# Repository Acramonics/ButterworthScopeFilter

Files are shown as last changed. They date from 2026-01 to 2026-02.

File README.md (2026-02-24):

ScopeFilter
===========

Andrew Martin, Acramonics, January 2026
---------------------------------------

This ScopeFilter is designed for putting in front of an oscilloscope
when doing audio work where there is HF interference from computers,
etc. It is a simple Active Butterworth dual 2nd order filter with a
cutoff of 50kHz.

It is powered by a standard 9v wallwart with the power supply section
taken from the Elektor ESR meter giving positive and negative 4.5v
rails.

Filter component values are calculated from
https://www.changpuak.ch/electronics/Butterworth_Lowpass_active_24dB.php
and tweaked to standard values. As specified, the filter starts to cut
off at 40kHz.

The `LTSpice` directory contains an LTSpice simulation showing the
frequency response. The Kicad Spice simulator seems to have difficulty
with dual rail power supplies.

The `FrontPanelDesigner` directory contains a simple front panel
layout for use with a small aluminium case (W:3.25" H:1.25" x D:4").
The software is available from schaeffer-ag.de/en/front-panel-designer

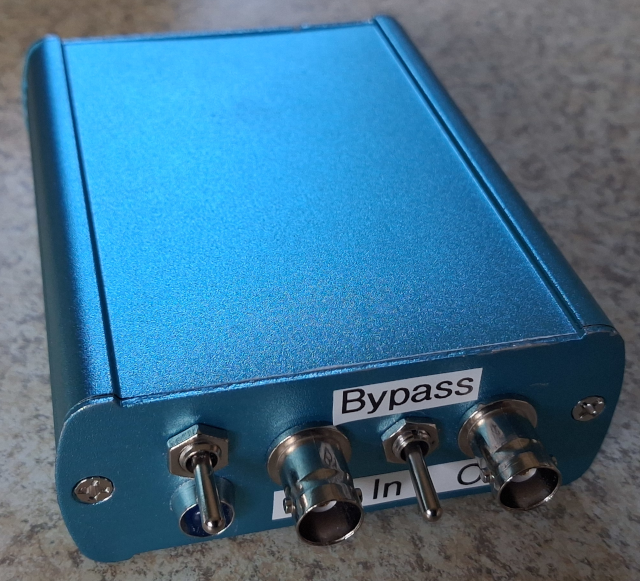
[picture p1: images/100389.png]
Front/top view

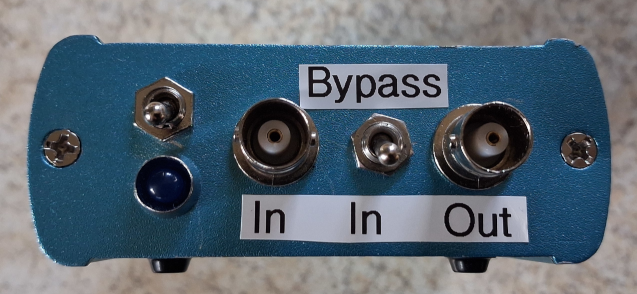
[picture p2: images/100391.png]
Front view

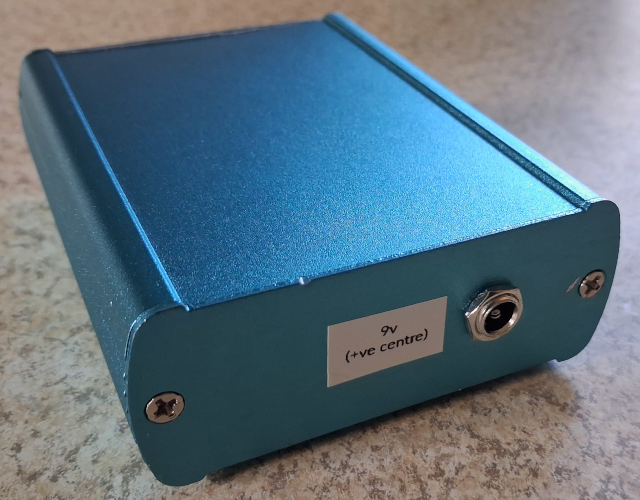
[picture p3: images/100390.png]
Rear view


I built the filter without Molex 254s for any of the wires except the
power input. This is the only one that comes from the back making it
convenient (with long enough wires) to be able to take off the front
panel (which is closely connected to the PCB) and unplug the power
from the board.

These images are generated by Kicad:

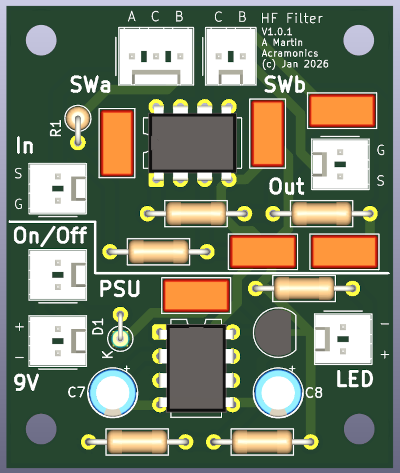
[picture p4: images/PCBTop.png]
PCB top view

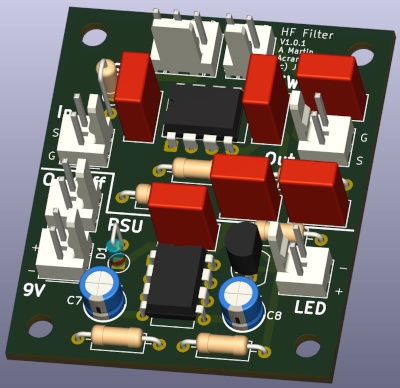
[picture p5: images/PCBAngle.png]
PCB andgle view


With the exception of the two 100nF caps, I also ended up building the
board with 5mm ceramic caps in place of the box film caps shown.

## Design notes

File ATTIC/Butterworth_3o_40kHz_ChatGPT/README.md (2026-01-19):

Filter type: 3rd-order Butterworth LPF

Cutoff: 40 kHz

Order:

2nd-order Sallen-Key (Q = 0.707)

1st-order active pole

Roll-off: −60 dB/decade

Op-amp GBW: ≥ 5 MHz recommended

Op-Amp Requirements (Important)
Because 40 kHz is relatively high for active filters:

GBW ≥ 5 MHz

Slew Rate ≥ 5 V/µs

✅ Recommended:

OPA2134

TL072

NE5532

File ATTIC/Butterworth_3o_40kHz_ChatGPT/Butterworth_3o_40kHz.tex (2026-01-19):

\documentclass[border=10pt]{standalone}
\usepackage{circuitikz}
\usepackage{siunitx}

\begin{document}

\begin{circuitikz}[american]

% ---------- Stage 1: 2nd-order Sallen-Key Butterworth ----------

\node (Vin) at (0,0) {$V_{in}$};
\draw (Vin) to[short] (1,0);

\draw (1,0) to[R=$R_1\,3.9\,\mathrm{k}\Omega$] (3,0);
\draw (3,0) to[R=$R_2\,3.9\,\mathrm{k}\Omega$] (5,0);

\draw (3,0) to[C=$C_1\,1\,\mathrm{nF}$] (3,-2) node[ground]{};
\draw (5,0) to[C=$C_2\,1\,\mathrm{nF}$] (5,-2) node[ground]{};

\draw (5,0) to[short] (6,0);

\node[op amp] (op1) at (7.5,-1) {};
\draw (6,0) |- (op1.+);

\draw (op1.-) to[R=$R_g\,10\,\mathrm{k}\Omega$] (6,-3) node[ground]{};
\draw (op1.out) to[R=$R_f\,5.9\,\mathrm{k}\Omega$] (op1.-);

\draw (op1.out) to[short] (9, -1) node[right]{$V_1$};

% ---------- Stage 2: 1st-order Active LPF ----------

\draw (9,-1) to[R=$R_3\,3.9\,\mathrm{k}\Omega$] (11,-1);
\draw (11,-1) to[C=$C_3\,1\,\mathrm{nF}$] (11,-3) node[ground]{};

\node[op amp] (op2) at (13,-2) {};
\draw (11,-1) |- (op2.+);

\draw (op2.-) to[short] (12,-4) node[ground]{};
\draw (op2.out) to[short] (15,-2) node[right]{$V_{out}$};

\end{circuitikz}

\end{document}

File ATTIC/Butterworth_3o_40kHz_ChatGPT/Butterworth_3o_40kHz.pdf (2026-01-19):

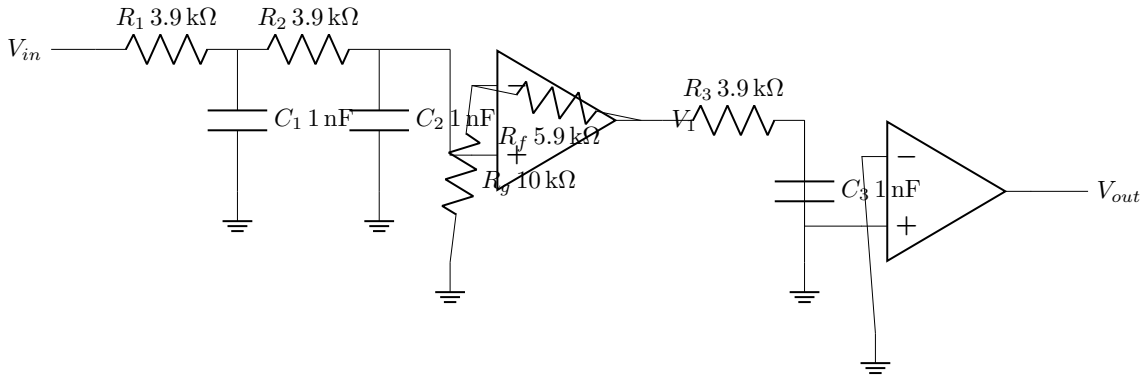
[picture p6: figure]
Vin; Vout

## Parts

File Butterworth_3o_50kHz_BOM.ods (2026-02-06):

Reference | Qty | Value | Footprint
C1,C2 | 2 | 3.3nF | Capacitor_THT:C_Rect_L7.0mm_W3.5mm_P5.00mm
C3 | 1 | 8.2nF | Capacitor_THT:C_Rect_L7.0mm_W3.5mm_P5.00mm
C4 | 1 | 1.2nF | Capacitor_THT:C_Rect_L7.0mm_W3.5mm_P5.00mm
C5,C6 | 2 | 100nF | Capacitor_THT:C_Rect_L7.0mm_W3.5mm_P5.00mm
C7 | 1 | 10uF | Capacitor_THT:CP_Radial_D5.0mm_P2.00mm
C8 | 1 | 22uF | Capacitor_THT:CP_Radial_D5.0mm_P2.00mm
D1 | 1 | 1N4007 | Diode_THT:D_DO-35_SOD27_P2.54mm_Vertical_AnodeUp
D2 | 1 | LED
J1,J2,J4,J5,J6,J7 | 6 | Conn_01x02_Pin | Connector_Molex:Molex_KK-254_AE-6410-02A_1x02_P2.54mm_Vertical
J3 | 1 | Conn_01x03_Pin | Connector_Molex:Molex_KK-254_AE-6410-03A_1x03_P2.54mm_Vertical
J8 | 1 | Barrel_Jack
R1 | 1 | 1K | Resistor_THT:R_Axial_DIN0207_L6.3mm_D2.5mm_P2.54mm_Vertical
R2,R3,R4 | 3 | 1K | Resistor_THT:R_Axial_DIN0207_L6.3mm_D2.5mm_P10.16mm_Horizontal
R5 | 1 | 680R | Resistor_THT:R_Axial_DIN0207_L6.3mm_D2.5mm_P10.16mm_Horizontal
R6 | 1 | 220R | Resistor_THT:R_Axial_DIN0207_L6.3mm_D2.5mm_P10.16mm_Horizontal
R7 | 1 | 330R | Resistor_THT:R_Axial_DIN0207_L6.3mm_D2.5mm_P10.16mm_Horizontal
SW1 | 1 | SW_DPDT_x2
SW2 | 1 | SW_SPST
U1 | 1 | TL072 | Package_DIP:DIP-8_W7.62mm
U2 | 1 | LM317L_TO92 | Package_TO_SOT_THT:TO-92_Inline
U3 | 1 | LMC7660 | Package_DIP:DIP-8_W7.62mm

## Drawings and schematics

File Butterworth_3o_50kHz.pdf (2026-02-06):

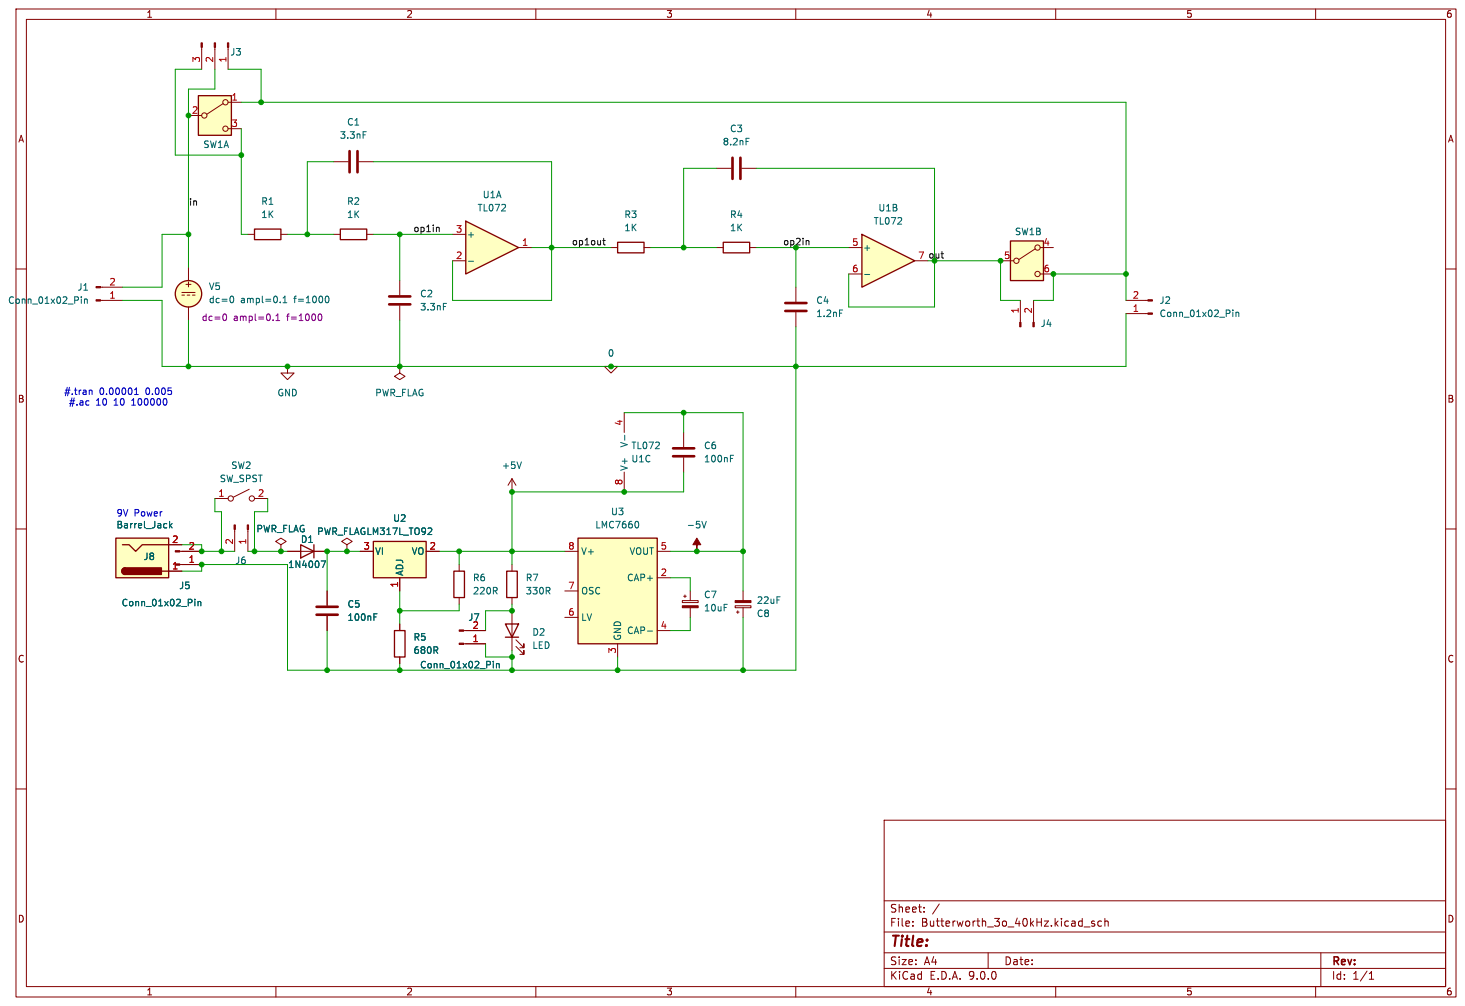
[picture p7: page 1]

Id: 1/1 Title: File: Butterworth_3o_40kHz.kicad_sch Sheet: /

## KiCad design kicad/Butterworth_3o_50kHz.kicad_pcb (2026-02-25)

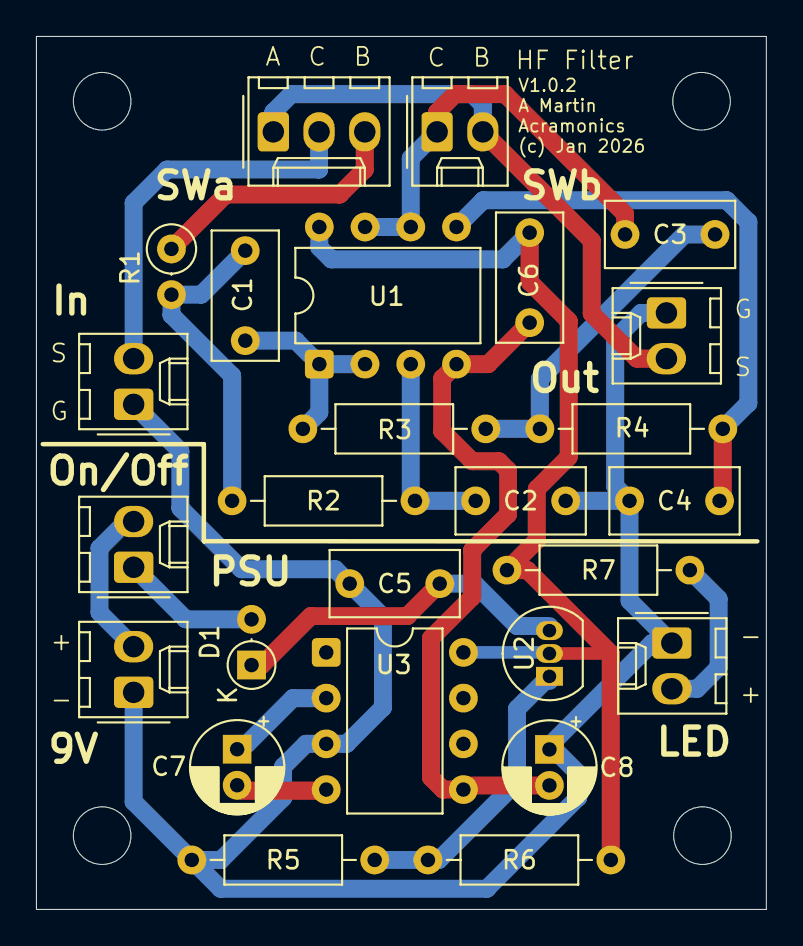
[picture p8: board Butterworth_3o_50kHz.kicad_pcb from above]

Board: 2 copper layers, 40.6 x 48.5 mm, 26 parts (0 on the bottom side), 19 nets.

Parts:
C1, C2: 3.3nF; C_Rect_L7.0mm_W3.5mm_P5.00mm
C3: 8.2nF; C_Rect_L7.0mm_W3.5mm_P5.00mm
C4: 1.2nF; C_Rect_L7.0mm_W3.5mm_P5.00mm
C5, C6: 100nF; C_Rect_L7.0mm_W3.5mm_P5.00mm
C7: 10uF; CP_Radial_D5.0mm_P2.00mm
C8: 22uF; CP_Radial_D5.0mm_P2.00mm
D1: 1N4007; D_DO-35_SOD27_P2.54mm_Vertical_AnodeUp
J1, J2, J4, J5, J6, J7: Conn_01x02_Pin; Molex_KK-254_AE-6410-02A_1x02_P2.54mm_Vertical
J3: Conn_01x03_Pin; Molex_KK-254_AE-6410-03A_1x03_P2.54mm_Vertical
R1: 1K; R_Axial_DIN0207_L6.3mm_D2.5mm_P2.54mm_Vertical
R2, R3, R4: 1K; R_Axial_DIN0207_L6.3mm_D2.5mm_P10.16mm_Horizontal
R5: 680R; R_Axial_DIN0207_L6.3mm_D2.5mm_P10.16mm_Horizontal
R6: 220R; R_Axial_DIN0207_L6.3mm_D2.5mm_P10.16mm_Horizontal
R7: 330R; R_Axial_DIN0207_L6.3mm_D2.5mm_P10.16mm_Horizontal
U1: TL072; DIP-8_W7.62mm
U2: LM317L_TO92; TO-92_Inline
U3: LMC7660; DIP-8_W7.62mm

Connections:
0: C2.2, C4.2, C5.2, C8.1, J1.1, J2.1, J5.1, J7.1, R5.2, U3.3 (GND)
+5V: C6.2, R6.1, R7.1, U1.8 (V+), U2.2 (VO), U3.8 (V+)
-5V: C6.1, C8.2, U1.4 (V-), U3.5 (VOUT)
/in: J1.2, J3.2
/op1in: C2.1, R2.2, U1.3 (+)
/op1out: C1.2, R3.1, U1.1, U1.2 (-)
/op2in: C4.1, R4.2, U1.5 (+)
/out: C3.2, J4.1, U1.6 (-), U1.7
unnamed: C1.1, R1.2, R2.1
unnamed: C3.1, R3.2, R4.1
unnamed: D1.2 (A), J6.1
unnamed: C5.1, D1.1 (K), U2.3 (VI)
unnamed: J2.2, J3.1, J4.2
unnamed: J3.3, R1.1
unnamed: J5.2, J6.2
unnamed: J7.2, R7.2
unnamed: R5.1, R6.2, U2.1 (ADJ)
unnamed: C7.1, U3.2 (CAP+)
unnamed: C7.2, U3.4 (CAP-)

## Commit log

2026-02-06 Added PDF schematic and BOM
    [Butterworth_3o_40kHz.kicad_pcb, Butterworth_3o_40kHz.kicad_sch, Butterworth_3o_40kHz_BOM.ods]
2026-02-22 Added annotation of the PSU section to the PCB
    [Butterworth_3o_40kHz.kicad_pcb]
2026-02-24 Added front panel design, Gerber zip and pictures for README
2026-02-24 Added images of the board from Kicad
2026-02-25 Corrected filenames to 50kHz instead of 40kHz
    [Butterworth_3o_50kHz.kicad_pcb, Butterworth_3o_50kHz.kicad_sch, Butterworth_3o_50kHz_BOM.ods]
